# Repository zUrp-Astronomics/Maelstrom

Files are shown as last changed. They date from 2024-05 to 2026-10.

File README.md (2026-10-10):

<!-- zurp-readme-header:begin — paste this block once, never again: the poster and the badges update themselves at each build of the site — do not edit it -->
<div align="center">

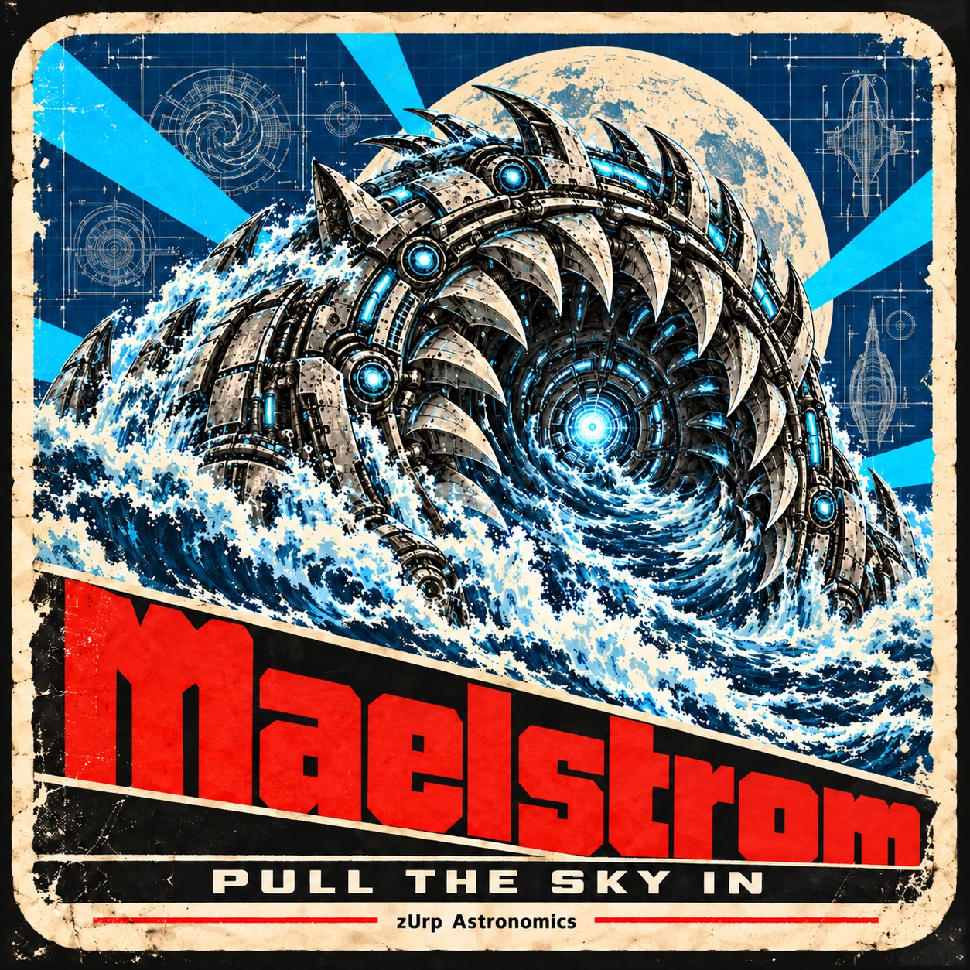
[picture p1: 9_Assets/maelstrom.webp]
zUrp Astronomics product poster



software licence
hardware licence

</div>

<!-- zurp-readme-header:end -->

<h1 align="center">Maelstrom</h1>

<p align="center"><strong><em>Pull the sky in.</em></strong></p>

<p align="center">
  <a href="https://zurp-astronomics.github.io/maelstrom/">Website</a> ·
  <a href="../../releases">Releases</a> ·
  <a href="https://github.com/zUrp-Astronomics">zUrp Astronomics</a>
</p>

---

<div align="center">

## 🚧 Work in progress — do not build yet 🚧

**Nothing here is validated on real hardware.**<br>
Files change without notice, and what you build today may need rework tomorrow.<br>
👀 Watch the repository to know when the first release lands.

</div>

---

## Why Maelstrom?

A cooled APS-C CCD astrocam usually costs more than a new CMOS camera. **Maelstrom cannibalises a
2006 DSLR instead**: the CCD of a Nikon D40 — APS-C, 6 Mpx, 7.8 µm pixels, the very sensor of the
QHY8 Pro — reborn behind active TEC cooling and a 16-bit readout chain, and headed for the body of
a ZWO planetary camera. Around **€40 per board**. Do the electronics yourself, and pull the sky in.

## At a glance

| | |
|---|---|
| Sensor | Nikon D40 CCD (Sony ICX453): APS-C, 6 Mpx, 7.8 µm pixels — same as the [QHY8 Pro](https://www.astroshop.de/fr/cameras-astronomiques/camera-qhy-8-pro-color/p,54748#specifications) |
| Readout | AD9826 16-bit ADC, FT2232H USB bridge, STM32F103 |
| Cooling | active TEC, opto-coupler and MOSFET isolated from the rest of the board |
| Boards | logic and power, v1.1 — round, 56 mm, components inside 48.5 mm |
| Link | USB type-B |
| Target body | the housing of a ZWO ASI224 planetary camera |
| Cost | 5 boards for €160 of fabrication, about €200 all in — around €40 each |

## Hardware

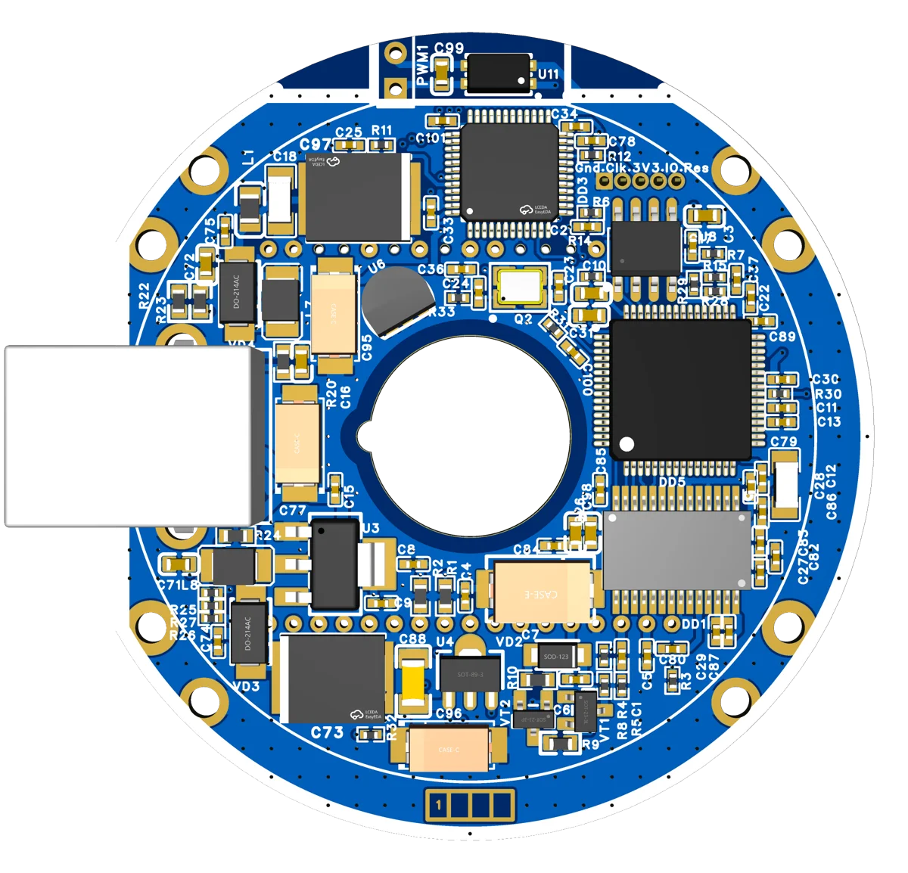
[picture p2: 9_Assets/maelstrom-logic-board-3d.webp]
Maelstrom logic board v1.1, 3D view


Maelstrom — formerly *Cam87 Redux* — starts from a design that already works: the author runs a
functional "box" version of the cam87. What it changes is the mechanics: three boards to assemble and
a fragile printed case become two round boards meant to fit the housing of a ZWO ASI224 — on
paper, it fits.

- **Layout.** Power, ADC, CCD horizontal and vertical drive and logic are kept as far apart as the
  56 mm allow; the supplies are decoupled with care, a capacitor wherever there was room.
- **Schematic updates.** Cooling redesigned around an isolated opto-coupler and MOSFET; decoupling
  added throughout; BoM reworked for cost and placement (down to 0402); back to a standard EEPROM.
- **Files.** Both v1.1 boards — logic and power — are in `1_Board/`; the cold plate, heatsink and
  camera design are in `2_Hardware/`. The source project is on
  [OSHWLab](https://oshwlab.com/lordzurp/cam87_redux).

## Status & roadmap

A variant is considered, with no file in this repository yet: a 48.5 mm round board, USB-C, and an
opto-coupler alone for the cooling, without the MOSFET.

## Credits

Maelstrom stands on the CAM86 and cam87 projects, which
pioneered the DSLR-sensor-reborn-as-astrocam approach; the cam87 is grim's (Gilmanov Rim).

## Repository layout

| Folder | Contents |
|---|---|
| [`0_Datasheets/`](0_Datasheets/) | datasheets of the components, as published by their makers |
| [`1_Board/`](1_Board/) | manufacturing files of the two v1.1 boards, one subfolder each: `Logic-board/`, `Power-board/` |
| [`2_Hardware/`](2_Hardware/) | mechanics: cold plate, heatsink, and the camera's design source (Fusion 360, STEP) |
| [`4_Firmware/`](4_Firmware/) | the cam87 STM32 firmware binary and the MProg template of the FT2232H EEPROM |
| [`5_App/`](5_App/) | Windows tools: FTDI MProg, and the cam87 viewer |
| [`8_References/`](8_References/) | external references: CAM86 and cam87 schematics, QHY8 Pro pictures |
| [`9_Assets/`](9_Assets/) | the showcase: product sheet, poster and README images |

## License

- **Hardware design** — boards, mechanics and 3D models: [Open Community License v1.1](LICENSE-HARDWARE).
- **Everything else** — firmware, software, documentation and images: [GNU GPL v3.0](LICENSE).

Third-party material keeps its own licence:

- the datasheets in `0_Datasheets/` and the documents in `8_References/` belong to their authors;
- MProg and its DLLs (`5_App/MProg 3.5 Release/`) are under FTDI's licence (`EULA.txt` in their folder);
- the viewer (`5_App/Viewer/`) and the firmware `4_Firmware/cam87 v1.0.bin` come from grim's (Gilmanov Rim) cam87, published without a licence; the `ftd2xx.dll` next to the viewer is FTDI's D2XX DLL;
- `4_Firmware/cam87.ept`, the MProg template of the cam87's FT2232H EEPROM, comes from the cam87 forums — most likely astroclub.kiev.ua, where grim's project was born (probable, not confirmed) — with no known licence.

---

<p align="center"><sub><a href="https://zurp-astronomics.github.io/">zUrp Astronomics</a> — a subsidiary of zUrp Industries. Because buying is cheating.</sub></p>

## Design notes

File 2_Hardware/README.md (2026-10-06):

La mécanique hors carte : la cold plate et le radiateur en STEP (avec le plan PDF du dessus de la cold plate), et la source de conception de la caméra, `Maelstrom_Camera`, en F3D et en STEP.

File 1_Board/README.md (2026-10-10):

Les fichiers de fabrication des deux cartes v1.1, tels que les sort l'outil de CAO : la carte logique dans `Logic-board/`, la carte d'alimentation dans `Power-board/`, chacune avec sa fiche `_0-README.txt`.

## Nommage des fichiers de carte

Les fichiers de `1_Board/` suivent le schéma :

```
Maelstrom-<Carte>-v<version>_<n>-<Nature>.<ext>
```

- `<Carte>` : `Logic-board` ou `Power-board`, le nom du sous-dossier ;
- `<version>` : la version de la carte, `1.1` ;
- `<n>-<Nature>` : la nature du fichier.

| n | fichier |
|---|---|
| 0 | `0-README.txt` : la fiche de la carte |
| 1 | `1-Schematics.pdf`, `1-Schematics.png` : le schéma |
| 2 | `2-view_top.png`, `2-view_bot.png` : vues du dessus et du dessous ; `2-view_3D.png`, `2-view_3D-bot.png`, `2-view_3D.step` : vues 3D du dessus et du dessous, et modèle 3D |
| 3 | `3-Gerber.zip` : Gerber RS-274X et perçages Excellon |
| 4 | `4-BoM.xlsx` : la nomenclature, références LCSC |
| 5 | `5-PnP.xlsx` : le placement, coordonnées en mm |

Exemple : `Maelstrom-Logic-board-v1.1_3-Gerber.zip`.

Les autres fichiers gardent leur nom : ceux de `2_Hardware/` (`Maelstrom_<Pièce>.<ext>`), et les
fichiers de tiers (datasheets, documents de référence, firmware, MProg, viewer).

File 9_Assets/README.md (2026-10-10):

# 9_Assets

The showcase of Maelstrom: what the [zUrp Astronomics website](https://zurp-astronomics.github.io/maelstrom/) and this repository's
README display. It belongs to the zUrp Astronomics organisation, which keeps it consistent across
all its products.

| File | What it is | Shown on |
|---|---|---|
| `zurp.yml` | the product sheet: name, tagline, slogan, section, status, description, accent colour | the website, the organisation README |
| `maelstrom.webp` | the poster, 1254 × 1254 | the website, the README header |
| `maelstrom-logic-board-3d.webp` | logic board v1.1, 3D view | the README |

Images here are WebP copies sized for display. Their full-size originals stay where they are produced: `1_Board/Logic-board/Maelstrom-Logic-board-v1.1_2-view_3D.png`.

The sheet is read and checked by the website at each build: its format is described in
[`content/README.md`](https://github.com/zUrp-Astronomics/zurp-astronomics.github.io/blob/main/content/README.md)
of the website's repository.

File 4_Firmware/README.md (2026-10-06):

Le firmware de la carte : le binaire STM32 de la cam87 (`cam87 v1.0.bin`) et le gabarit MProg de l'EEPROM du FT2232H (`cam87.ept`).

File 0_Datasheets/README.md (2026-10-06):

Les datasheets des composants utilisés, sous leur nom d'origine : PDF du fabricant, plus la feuille de calcul du MC34063 et le brochage de l'ICX453.

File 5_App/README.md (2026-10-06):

Les applications qui parlent au produit, chacune dans son dossier d'origine : MProg de FTDI, pour programmer l'EEPROM du FT2232H, et le viewer de la cam87.

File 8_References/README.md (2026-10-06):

Ce que le projet consulte, pas ce qu'il produit : les schémas de la CAM86 et de la cam87, et des images de la QHY8pro.

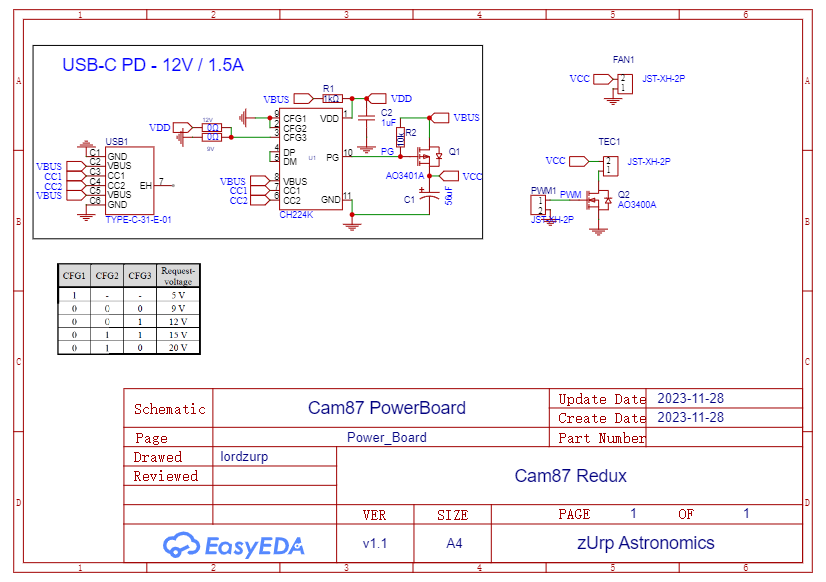
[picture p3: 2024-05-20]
1_Board/Power-board/Maelstrom-Power-board-v1.1_1-Schematics.png

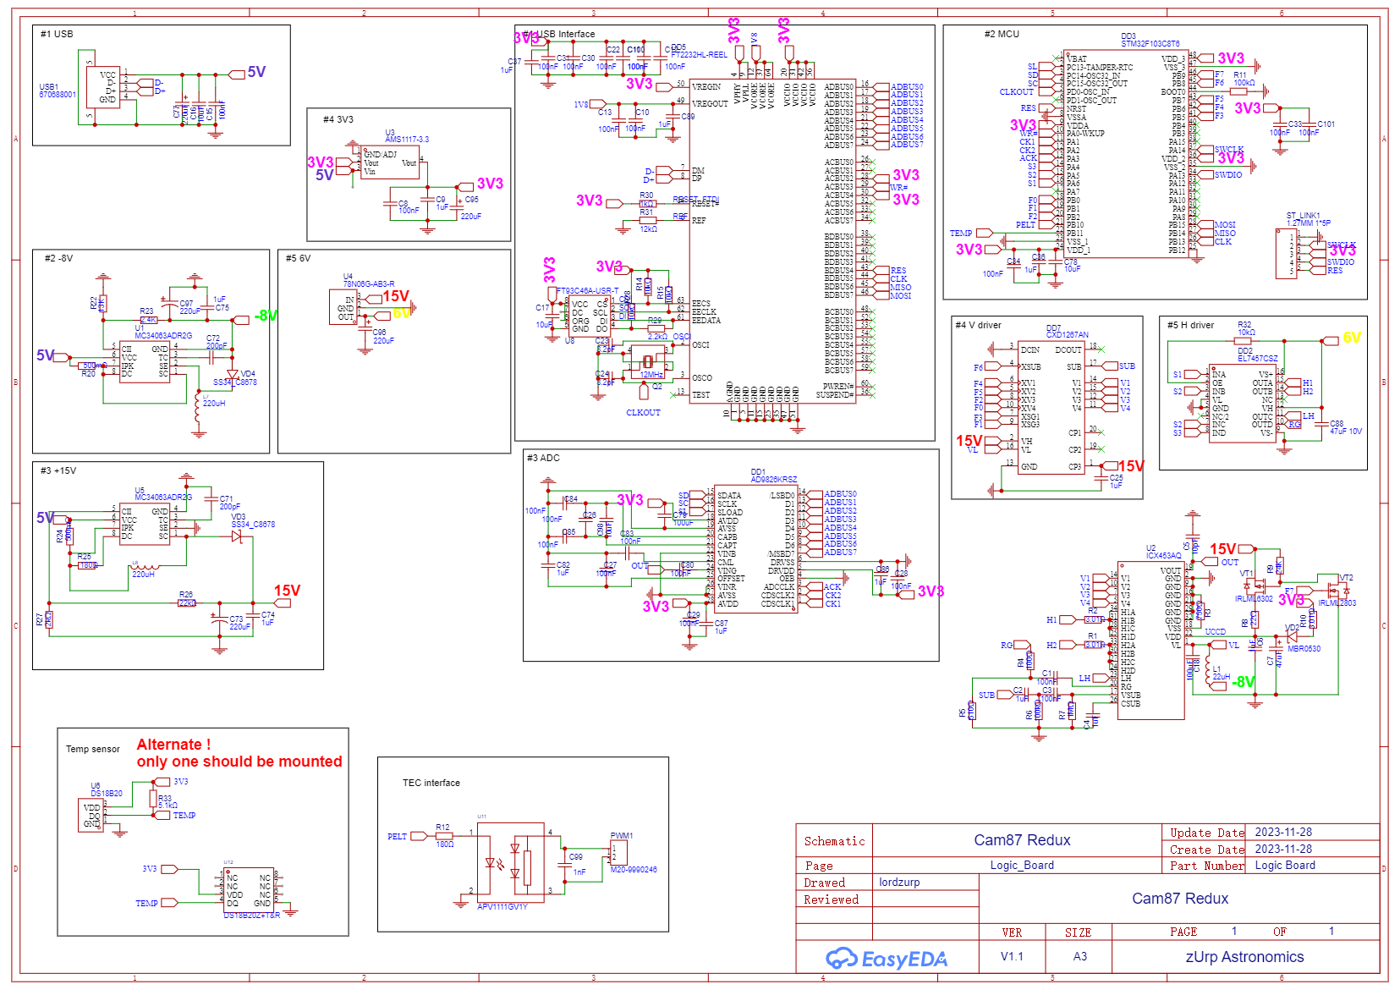
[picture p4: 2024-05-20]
1_Board/Logic-board/Maelstrom-Logic-board-v1.1_1-Schematics.png

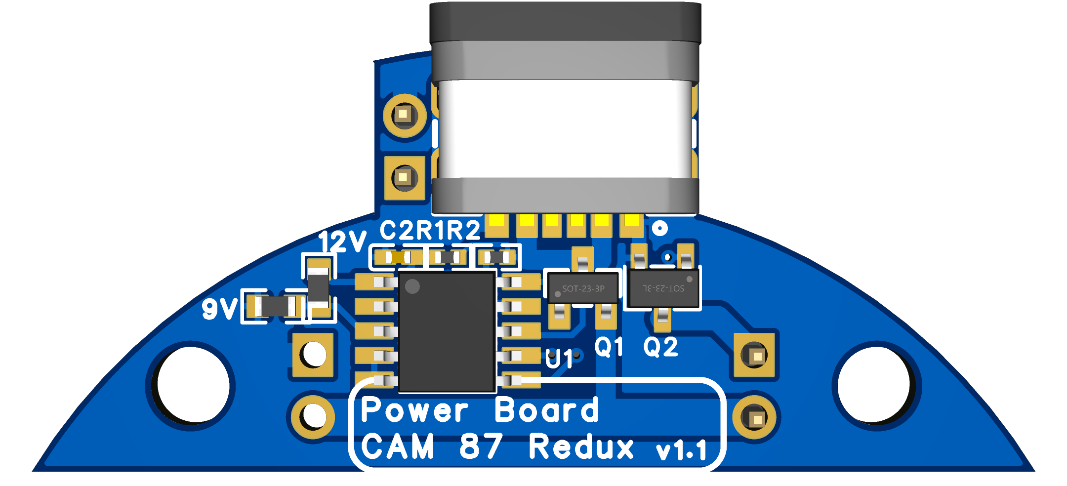
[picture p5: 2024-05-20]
1_Board/Power-board/Maelstrom-Power-board-v1.1_2-view_3D.png

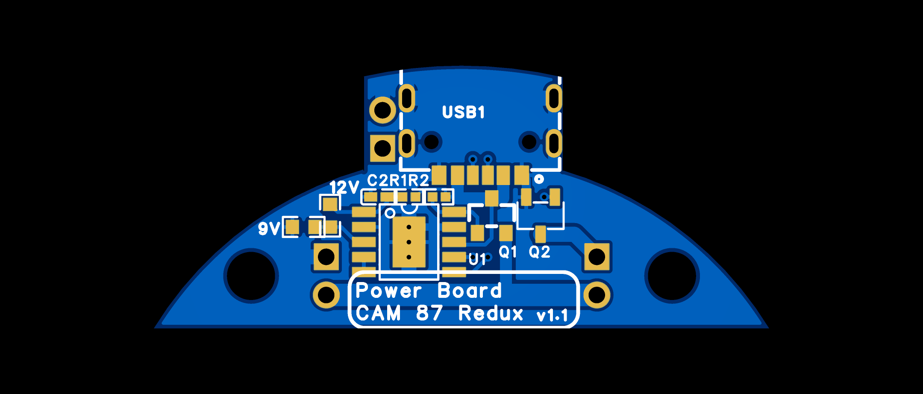
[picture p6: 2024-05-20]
1_Board/Power-board/Maelstrom-Power-board-v1.1_2-view_top.png

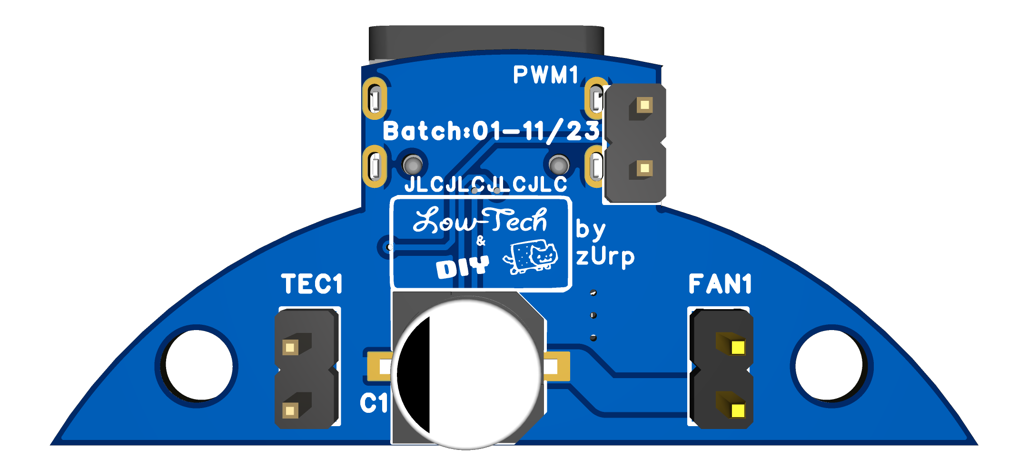
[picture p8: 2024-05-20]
1_Board/Power-board/Maelstrom-Power-board-v1.1_2-view_3D-bot.png

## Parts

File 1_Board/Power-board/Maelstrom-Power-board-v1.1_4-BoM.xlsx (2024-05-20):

No. | Quantity | Device | Designator | Footprint | Value | Manufacturer Part | Manufacturer | Supplier Part | Supplier | Add into BOM | Name | Primary Category | Secondary Category | JLCPCB Stock | JLCPCB Price | JLCPCB Part Class
1 | 1 | 0603WAF0000T5E | 12V | R0603 | 0Ω | 0603WAF0000T5E | UNI-ROYAL(厚声) | C21189 | LCSC | yes | 0Ω | Resistors | Chip Resistor - Surface Mount | 9418308 | 0.00645 | Basic Part
2 | 1 | OVZ560M1ETR-0606 | C1 | CAP-SMD_BD6.3-L6.6-W6.6-FD-A | 56uF | OVZ560M1ETR-0606 | lelon(立隆) | C250116 | LCSC | yes | 56uF |  |  | 635 | 1.237 | ExtendedPart
3 | 1 | CL05A105KA5NQNC | C2 | C0402 | 1uF | CL05A105KA5NQNC | SAMSUNG(三星) | C52923 | LCSC | yes | 1uF |  |  | 2774039 | 0.0237 | BasicPart
4 | 3 | JST-XH-2P-M | FAN1,PWM1,TEC1 | HDR-M-2.54_1X2 |  | JST-XH-2P-M | JST | JST-XH-2P-M |  | yes | JST-XH-2P |  |  | 0
5 | 1 | AO3401A_C15127 | Q1 | SOT-23_L2.9-W1.3-P1.90-LS2.4-BR |  | AO3401A | AOS | C15127 | LCSC | yes | AO3401A | Triode/MOS Tube/Transistor | MOSFETs | 235251 | 0.394 | BasicPart
6 | 1 | AO3400A_C20917 | Q2 | SOT-23-3_L2.9-W1.6-P1.90-LS2.8-BR |  | AO3400A | AOS | C20917 | LCSC | yes | AO3400A | Triode/MOS Tube/Transistor | MOSFETs | 30849 | 0.488 | BasicPart
7 | 1 | 0402WGF1001TCE | R1 | R0402 | 1kΩ | 0402WGF1001TCE | UNI-ROYAL(厚声) | C11702 | LCSC | yes | 1kΩ | Resistors | Chip Resistor - Surface Mount | 5855534 | 0.0031 | BasicPart
8 | 1 | 0402WGF1002TCE | R2 | R0402 | 10k | 0402WGF1002TCE | UNI-ROYAL(厚声) | C25744 | LCSC | yes |  |  |  | 8885566 | 0.00292 | BasicPart
9 | 1 | CH224K | U1 | ESSOP-10_L4.9-W3.9-P1.0-LS6.0-TL-EP |  | CH224K | WCH(南京沁恒) | C970725 | LCSC | yes | CH224K | Communication Interface Chip/UART/485/232 | USB ICs | 3287 | 3.22 | ExtendedPart
10 | 1 | TYPE-C-31-E-01 | USB1 | TYPE-C-SMD_TYPE-C-31-E-01 |  | TYPE-C-31-E-01 | 韩国韩荣 | C530618 | LCSC | yes | TYPE-C-31-E-01 |  |  | 128 | 5.94 | ExtendedPart

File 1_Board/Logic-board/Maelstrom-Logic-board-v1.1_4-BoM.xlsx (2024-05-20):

No. | Quantity | Device | Designator | Footprint | Value | Manufacturer Part | Manufacturer | Supplier Part | Supplier | Add into BOM | Name | Primary Category | Secondary Category | JLCPCB Stock | JLCPCB Price | JLCPCB Part Class
1 | 20 | CL05B104KB54PNC | C1,C3,C8,C11,C12,C13,C15,C22,C27,C28,C29,C30,C33,C34,C80,C83,C84,C85,C100,C101 | C0402 | 100nF | CL05B104KB54PNC | SAMSUNG(三星) | C307331 | LCSC | yes | 100nF | Capacitors | Multilayer Ceramic Capacitors MLCC - SMD/SMT | 3210689 | 0.0428 | Basic Part
2 | 13 | CL05A105KA5NQNC | C2,C4,C6,C9,C25,C36,C37,C74,C75,C82,C86,C87,C89 | C0402 | 1uF | CL05A105KA5NQNC | SAMSUNG(三星) | C52923 | LCSC | yes | 1uF |  |  | 2776105 | 0.0237 | Basic Part
3 | 1 | CL05C100JB5NNNC | C5 | C0402 | 10pF | CL05C100JB5NNNC | SAMSUNG(三星) | C32949 | LCSC | yes | 10pF |  |  | 187520 | 0.0343 | Basic Part
4 | 1 | TAJD476K025RNJ | C7 | CAP-SMD_L7.3-W4.3-R-RD |  | TAJD476K025RNJ | AVX | C7228 | LCSC | yes | 47uF |  |  | 9636 | 3.8 | Extend
5 | 3 | CC0603KRX7R9BB104 | C10,C26,C31 | C0603 | 100nF | CC0603KRX7R9BB104 | YAGEO(国巨) | C14663 | LCSC | yes | 100nF |  |  | 26465158 | 0.0142 | Basic Part
6 | 3 | CL10A106KP8NNNC | C16,C17,C98 | C0603 | 10uF | CL10A106KP8NNNC | SAMSUNG(三星) | C19702 | LCSC | yes | 10uF |  |  | 2289457 | 0.0338 | Basic Part
7 | 2 | CL31A107MQHNNNE | C18,C79 | C1206 | 100uF | CL31A107MQHNNNE | SAMSUNG(三星) | C15008 | LCSC | yes | 100uF |  |  | 97979 | 0.398 | Basic Part
8 | 2 | 0402CG8R2C500NT | C23,C24 | C0402 | 8.2pF | 0402CG8R2C500NT | FH(风华) | C1579 | LCSC | yes | 8.2pF |  |  | 18688 | 0.0064 | Extended Part
9 | 2 | 0603B201K500NT | C71,C72 | C0603 |  | 0603B201K500NT | FH | C1600 | LCSC | yes | 200pF |  |  | 46770 | 0.0227 | Basic
10 | 2 | TCN4227M025R0100 | C73,C97 | CAP-SMD_L7.3-W6.1_TCN4227M025R0100 | 220uF | TCN4227M025R0100 | Kyocera AVX | C2158994 | LCSC | yes | 220uF | Capacitors | Tantalum Capacitors | 763 | 18.69 | Extended Part
11 | 3 | TAJC227K010RNJ | C77,C95,C96 | CAP-SMD_L6.0-W3.2-R-RD | 220uF | TAJC227K010RNJ | Kyocera AVX | C8023 | LCSC | yes | 220uF |  |  | 564 | 3.22 | Extended Part
12 | 1 | CL05A106MQ5NUNC | C78 | C0402 | 10uF | CL05A106MQ5NUNC | SAMSUNG(三星) | C15525 | LCSC | yes | 10uF |  |  | 7094435 | 0.029 | Basic Part
13 | 1 | 47uF 10V | C88 | C1206 |  | CL31A476MPHNNNE | SAMSUNG | C96123 | LCSC | yes | 47uF 10V |  |  | 311116 | 0.466 | Basic
14 | 1 | CL10B102KB8NNNC | C99 | C0603 | 1nF | CL10B102KB8NNNC | SAMSUNG(三星) | C1588 | LCSC | yes | 1nF |  |  | 5179975 | 0.0169 | Basic Part
15 | 1 | AD9826KRSZ | DD1 | SSOP-28_L10.2-W5.3-P0.65-LS7.8-BL |  | AD9826KRSZ | ADI | C13734 | LCSC | yes | AD9826KRSZ |  |  | 1754 | 38.09 | Extend
16 | 1 | EL7457CSZ | DD2 | SOIC-16_L9.9-W3.9-P1.27-LS6.0-BL |  | EL7457CSZ | RENESAS(瑞萨)/IDT | C3655423 | LCSC | yes | EL7457CSZ |  |  | 0 | 49.68
17 | 1 | STM32F103C8T6 | DD3 | LQFP-48_L7.0-W7.0-P0.50-LS9.0-BL |  | STM32F103C8T6 | STMicroelectronics | C8734 | LCSC | yes | STM32F103C8T6 |  |  | 56433 | 8.93 | Basic
18 | 1 | FT2232HL-REEL | DD5 | LQFP-64_L10.0-W10.0-P0.50-LS12.0-TL |  | FT2232HL-REEL | FTDI(飞特帝亚) | C27882 | LCSC | yes | FT2232HL-REEL |  |  | 59 | 36.83 | Extended Part
19 | 1 | CXD1267AN | DD7 | TSSOP-20_L6.5-W4.4-P0.65-LS6.4-BL |  | Sony |  |  |  | yes | CXD1267AN
20 | 1 | CBC2012T220K | L1 | L0805 | 22uH | CBC2012T220K | TAIYO YUDEN(太诱) | C223184 | LCSC | yes | 22uH |  |  | 7 | 0.786 | Extended Part
21 | 2 | CBC3225T221KR | L7,L8 | L1210 | 220uH | CBC3225T221KR | TAIYO YUDEN(太诱) | C223231 | LCSC | yes | 220uH | Inductors/Coils/Transformers | Power Inductors | 262 | 0.642 | Extended Part
22 | 1 | 12MHz | Q2 | OSC-SMD_4P-L3.2-W2.5-BL |  | X322512MSB4SI | YXC | C9002 | LCSC | yes | 12MHz |  |  | 201387 | 0.372 | Basic
23 | 3 | 0603WAF301KT5E | R1,R2,R10 | R0603 | 3.01Ω | 0603WAF301KT5E | UNI-ROYAL(厚声) | C270936 | LCSC | yes | 3.01Ω |  |  | 28 | 0.0124 | Extended Part
24 | 1 | AC0402FR-07750RL | R3 | R0402 | 750Ω | AC0402FR-07750RL | YAGEO(国巨) | C227221 | LCSC | yes | 750Ω |  |  | 7573 | 0.0066 | Extended Part
25 | 1 | 0402WGF1000TCE | R4 | R0402 | 100Ω | 0402WGF1000TCE | UNI-ROYAL(厚声) | C25076 | LCSC | yes | 100Ω |  |  | 2005191 | 0.00292 | Basic Part
26 | 1 | 0402WGF5100TCE | R5 | R0402 | 510Ω | 0402WGF5100TCE | UNI-ROYAL(厚声) | C25123 | LCSC | yes | 510Ω |  |  | 386746 | 0.00303 | Basic Part
27 | 2 | 0402WGF1003TCE | R6,R11 | R0402 | 100kΩ | 0402WGF1003TCE | UNI-ROYAL(厚声) | C25741 | LCSC | yes | 100kΩ |  |  | 3170292 | 0.00301 | Basic Part
28 | 1 | 0402WGF1004TCE | R7 | R0402 | 1MΩ | 0402WGF1004TCE | UNI-ROYAL(厚声) | C26083 | LCSC | yes | 1MΩ |  |  | 1271919 | 0.00322 | Basic Part
29 | 1 | 0402WGF220JTCE | R8 | R0402 | 22Ω | 0402WGF220JTCE | UNI-ROYAL(厚声) | C25092 | LCSC | yes | 22Ω |  |  | 1354420 | 0.00305 | Basic Part
30 | 1 | 0603WAF2402T5E | R9 | R0603 |  | 0603WAF2402T5E | UniOhm | C23352 | LCSC | yes | 24K |  |  | 554806 | 0.00625 | Basic
31 | 2 | CRCW0402180RFKED | R12,R25 | R0402 | 180Ω | CRCW0402180RFKED | VISHAY(威世) | C481962 | LCSC | yes | 180Ω |  |  | 2673 | 0.04 | Extended Part
32 | 4 | 0402WGF1002TCE | R14,R15,R28,R32 | R0402 | 10kΩ | 0402WGF1002TCE | UNI-ROYAL(厚声) | C25744 | LCSC | yes | 10kΩ |  |  | 8896301 | 0.00292 | Basic Part
33 | 2 | HP03W5F500LT5E | R20,R24 | R0603 | 500mΩ | HP03W5F500LT5E | UNI-ROYAL(厚声) | C414986 | LCSC | yes | 500mΩ |  |  | 2025 | 0.202 | Extended Part
34 | 1 | 0603WAF1302T5E | R22 | R0603 |  | 0603WAF1302T5E | UniOhm | C22797 | LCSC | yes | 13K |  |  | 313642 | 0.00617 | Basic
35 | 1 | 0603WAF2401T5E | R23 | R0603 |  | 0603WAF2401T5E | UniOhm | C22940 | LCSC | yes | 2.4K |  |  | 306378 | 0.00609 | Basic
36 | 1 | 0402WGF2202TCE | R26 | R0402 | 22kΩ | 0402WGF2202TCE | UNI-ROYAL(厚声) | C25768 | LCSC | yes | 22kΩ |  |  | 530038 | 0.00306 | Basic Part
37 | 1 | 0402WGF2001TCE | R27 | R0402 | 2kΩ | 0402WGF2001TCE | UNI-ROYAL(厚声) | C4109 | LCSC | yes | 2kΩ |  |  | 2420582 | 0.00303 | Basic Part
38 | 1 | 0402WGF2201TCE | R29 | R0402 | 2.2kΩ | 0402WGF2201TCE | UNI-ROYAL(厚声) | C25879 | LCSC | yes | 2.2kΩ |  |  | 795002 | 0.0031 | Basic Part
39 | 1 | 0402WGF1001TCE | R30 | R0402 | 1kΩ | 0402WGF1001TCE | UNI-ROYAL(厚声) | C11702 | LCSC | yes | 1kΩ |  |  | 5857364 | 0.0031 | Basic Part
40 | 1 | 0402WGF1202TCE | R31 | R0402 | 12kΩ | 0402WGF1202TCE | UNI-ROYAL(厚声) | C25752 | LCSC | yes | 12kΩ |  |  | 459663 | 0.00311 | Basic Part
41 | 1 | 0402WGF5101TCE | R33 | R0402 | 5.1kΩ | 0402WGF5101TCE | UNI-ROYAL(厚声) | C25905 | LCSC | yes | 5.1kΩ |  |  | 1149428 | 0.00315 | Basic Part
42 | 2 | MC34063ADR2G | U1,U5 | SOIC-8_L5.0-W4.0-P1.27-LS6.0-BL |  | MC34063ADR2G | ON | C32078 | LCSC | yes | MC34063ADR2G |  |  | 18536 | 3.57 | Basic
43 | 1 | Sony | U2 | ICX453AQ |  | Sony |  |  |  | yes | ICX453AQ
44 | 1 | AMS1117-3.3 | U3 | SOT-223-3_L6.5-W3.4-P2.30-LS7.0-BR |  | AMS1117-3.3 | AMS | C6186 | LCSC | yes | AMS1117-3.3 |  |  | 383760 | 0.887 | Basic
45 | 1 | 78N06G-AB3-R | U4 | SOT-89-3_L4.5-W2.5-P1.50-LS4.2-BR |  | 78N06G-AB3-R | UTC | C84863 | LCSC | yes | 78N06G-AB3-R |  |  | 8726 | 0.359 | Extend
46 | 1 | FT93C46A-USR-T | U8 | SOP-8_L4.9-W3.9-P1.27-LS6.0-BL |  | FT93C46A-USR-T | FMD(辉芒微) | C2902369 | LCSC | yes | FT93C46A-USR-T | Memory | EEPROM | 150 | 0.692 | Extended Part
47 | 1 | APV1111GV1Y | U11 | SSOP-4_L4.5-W2.6-P1.27-LS4.8-TL |  | APV1111GV1Y | PANASONIC(松下) | C2977173 | LCSC | yes | APV1111GV1Y | Optocoupler/LED/Digital Tube/Photoelectric Device | Optocouplers - Logic Output | 301 | 21.94 | Extended Part
48 | 1 | DS18B20Z+T&R | U12 | SOIC-8_L4.9-W3.9-P1.27-LS6.0-BL |  | DS18B20Z+T&R | ADI(亚德诺)/MAXIM(美信) | C97190 | LCSC | yes | DS18B20Z+T&R | Sensors | Temperature Sensors | 2322 | 9.39 | Extended Part
49 | 1 | MBR0530T1G | VD2 | SOD-123_L2.8-W1.8-LS3.7-RD |  | MBR0530T1G | ON | C82046 | LCSC | yes | MBR0530 |  |  | 39033 | 0.654 | Extend
50 | 2 | SS34 | VD3,VD4 | DO-214AC_L4.3-W2.7-LS5.3-RD |  | SS34 | MDD | C8678 | LCSC | yes | SS34_C8678 |  |  | 964662 | 0.145 | Basic
51 | 1 | IRLML6302TRPBF | VT1 | SOT-23-3_L2.9-W1.6-P1.90-LS2.8-BR |  | IRLML6302TRPBF | IR | C24097 | LCSC | yes | IRLML6302 |  |  | 29721 | 0.831 | Extend
52 | 1 | IRLML2803TRPBF | VT2 | SOT-23-3_L2.9-W1.3-P1.90-LS2.4-BR |  | IRLML2803TRPBF | Infineon | C2590 | LCSC | yes | IRLML2803 |  |  | 0 | 0.733 | Extend

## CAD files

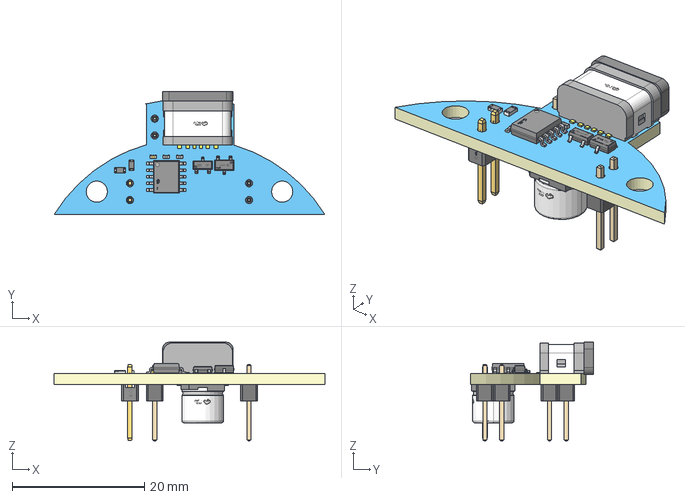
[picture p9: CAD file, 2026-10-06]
1_Board/Power-board/Maelstrom-Power-board-v1.1_2-view_3D.step
40.9 x 18.7 x 14.9 mm

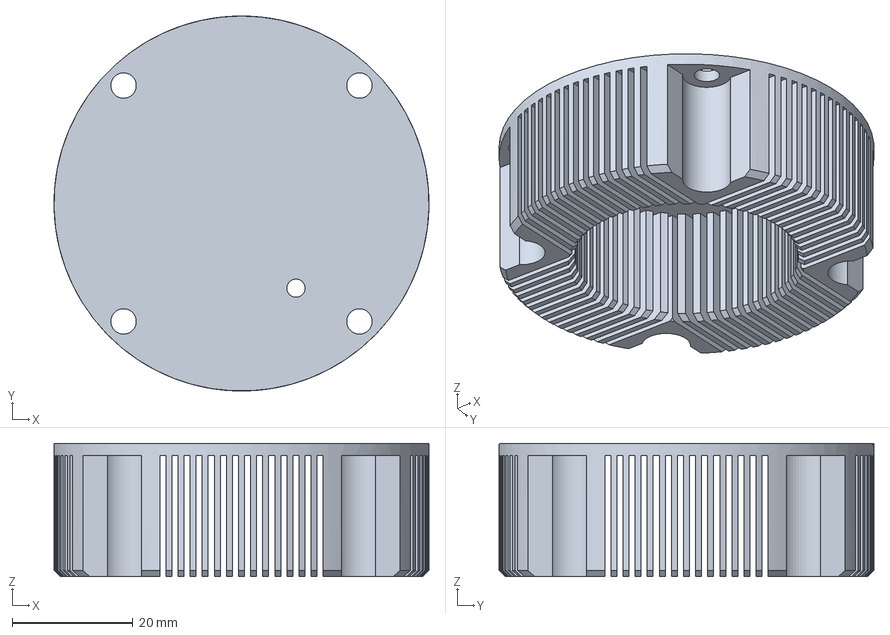
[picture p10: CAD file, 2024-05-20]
2_Hardware/Maelstrom_Camera.step
62.0 x 62.0 x 22.0 mm

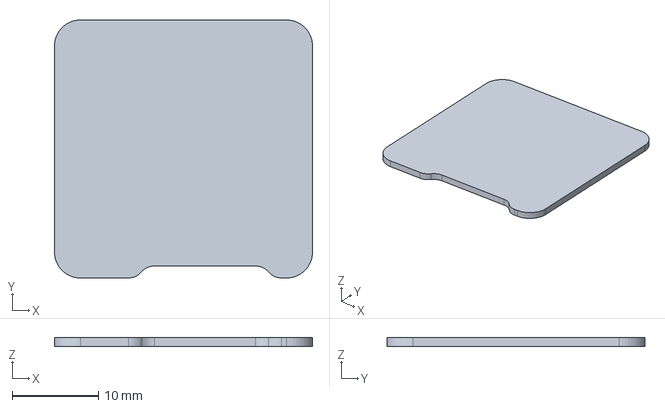
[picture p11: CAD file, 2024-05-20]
2_Hardware/Maelstrom_ColdPlate-BotPlate.step
30.0 x 30.0 x 1.00 mm

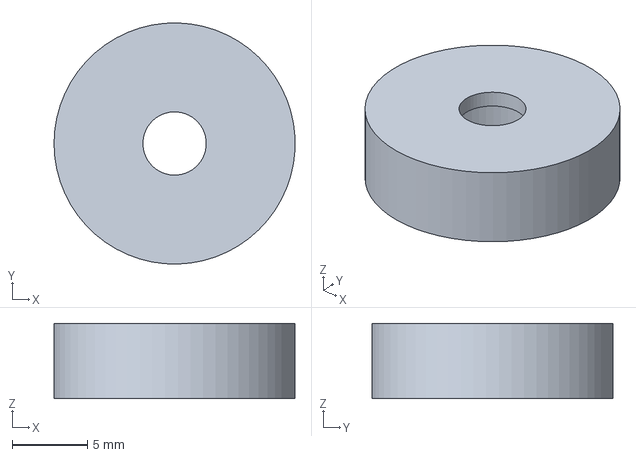
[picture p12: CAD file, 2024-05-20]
2_Hardware/Maelstrom_ColdPlate-BotCore.step
16.0 x 16.0 x 5.00 mm

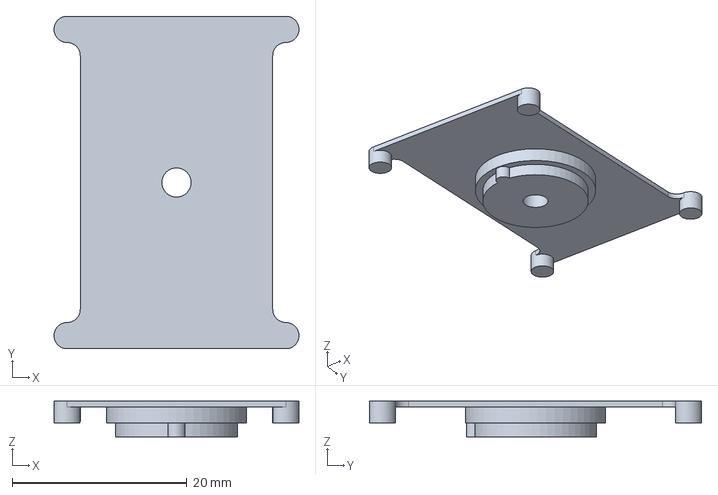
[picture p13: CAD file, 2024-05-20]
2_Hardware/Maelstrom_ColdPlate-Top.step
28.0 x 38.0 x 4.10 mm

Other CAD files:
2_Hardware/Maelstrom_Heatsink.step
2_Hardware/Maelstrom_Camera.f3d

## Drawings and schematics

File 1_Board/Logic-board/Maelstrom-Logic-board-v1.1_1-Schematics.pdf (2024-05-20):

### #1 USB

#4 3V3

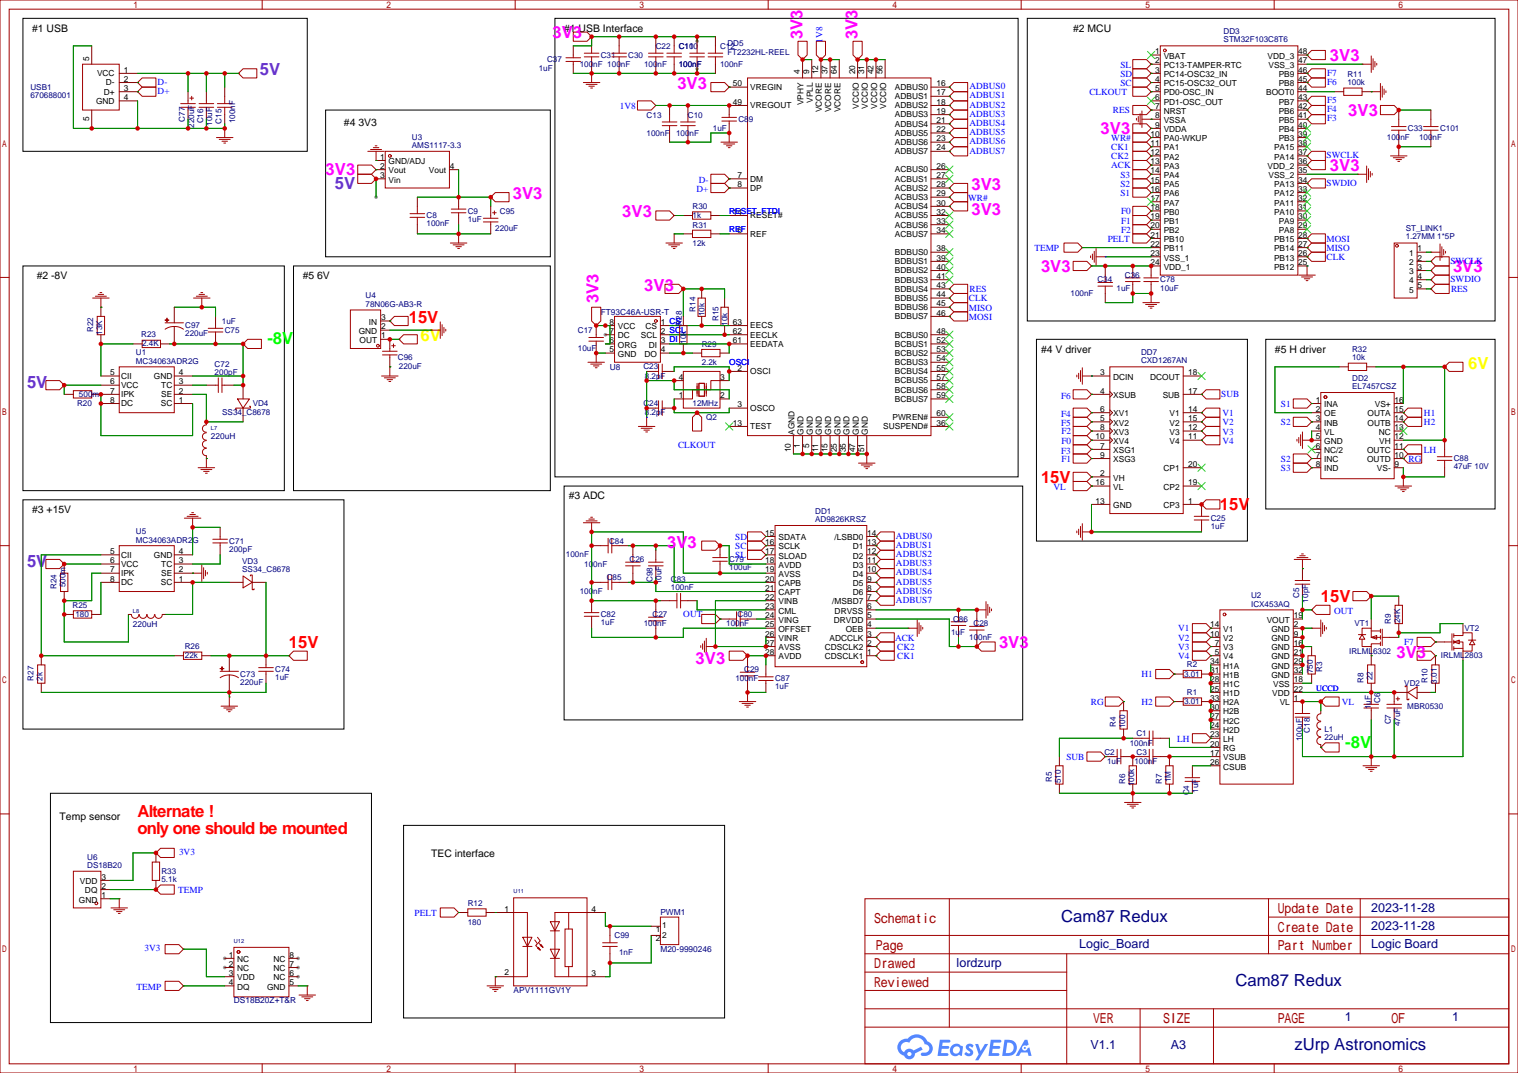
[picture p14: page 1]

only one should be mounted

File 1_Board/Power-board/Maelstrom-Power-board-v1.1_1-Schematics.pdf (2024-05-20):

# USB-C PD - 12V / 1.5A

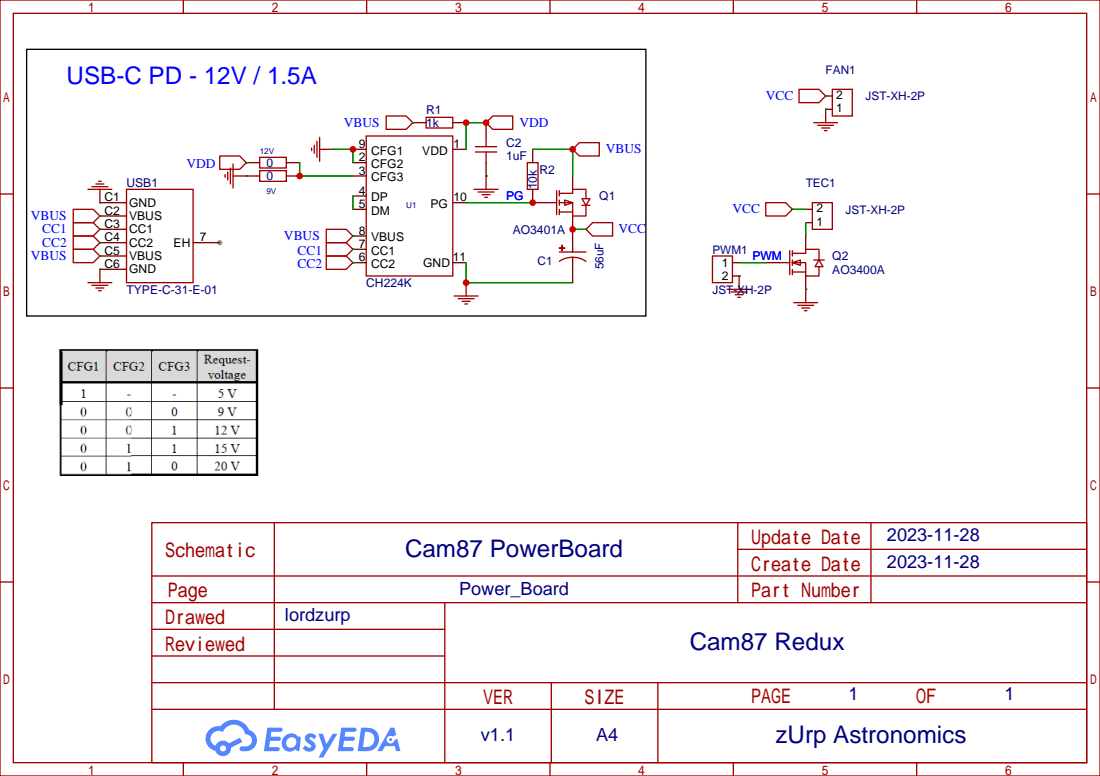
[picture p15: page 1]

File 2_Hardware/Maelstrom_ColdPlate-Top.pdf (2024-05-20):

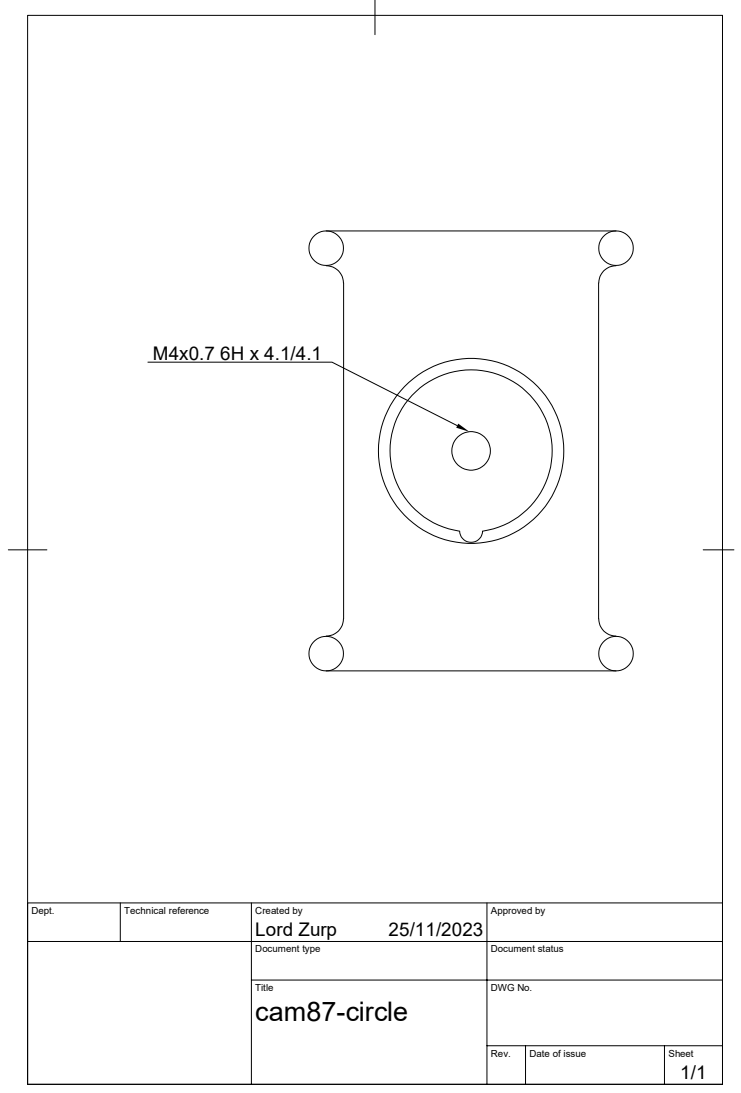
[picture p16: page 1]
Dept.; Technical reference; Created by; Approved by; Document type; Document status; Title; DWG No.; Rev.; Date of issue; Sheet; cam87-circle; Lord Zurp

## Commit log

2024-05-20 pop repo
    [Cam87_Redux - Cold_plate - bot_core.step, Cam87_Redux - Cold_plate - bot_plate.step, Cam87_Redux - Cold_plate - top.step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]
2026-10-03 chore(import-externe): déclaration de criticité (.lcars.json)
2026-10-03 ci(import): rail CI du depot (.gitea/workflows)
2026-10-06 feat(site): vitrine zUrp — 9_Assets/ et workflow zurp-site, posés tels quels depuis le kit du site
    Kit ready-room/site-maelstrom_workshop.zip (sha256 75985ee4…a68c),
    fichiers identiques à l'octet (sha256 vérifiés). Ticket #4.
    Claude-Session: https://claude.ai/code/session_01JkeaqfyitvVxvgP6FykwV1
2026-10-06 fix(site): zurp.yml — le statut est décidé par l'humain, pas par une release
    Corrige deux commentaires de 9_Assets/zurp.yml qui faisaient passer le
    produit en « released » dès qu'une release GitHub existe. Une release ne
    donne que la version affichée (son tag) et le rang dans la section ; le
    statut (wip | future | released) est écrit dans la fiche et décidé par
    l'humain. Données YAML inchangées.
    Claude-Session: https://claude.ai/code/session_01Qsyq5bGS8EnZmDohAf4kco
2026-10-06 refactor(repo): arborescence 0_…9_ au canon zUrp et README refondu
    - rangement par git mv (blobs inchangés) : 0_Datasheets, 1_Board/{Logic,Power}_board,
    2_Hardware, 3_3D-Models, 4_Firmware, 5_App, 8_References ;
    - fichiers de conception renommés Maelstrom_<Pièce>[_<version|date>][_<rang>_<doc>] ;
    - doublons à l'octet de la racine (Cam87_Redux.f3d/.step) supprimés ;
    - README : bloc d'en-tête zUrp en tête, texte de l'humain conservé,
    sections Arborescence et Licence.
    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
    [Cam87_Redux.f3d, Cam87_Redux.step, MC34063 DWS.XLS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]
2026-10-06 docs(readme): origine probable de cam87.ept — forums de la cam87, très probablement astroclub.kiev.ua
    Claude-Session: https://claude.ai/code/session_012NVZZjjQwiZYRfdeVsthva
2026-10-06 refactor(repo): mise au canon MAJ-DEPOTS-PRODUIT — cartes, 2_Hardware, README de dossier, licences, workflow
    - 1_Board : Logic-board/ et Power-board/, fichiers au schéma
    Maelstrom-<Carte>-v1.1_<n>-<Nature>.<ext> (git mv), fiche _0-README.txt par carte
    - 2_Hardware reçoit Maelstrom_Camera.f3d/.step ; 3_3D-Models disparaît,
    Maelstrom_PowerBoard_2024-03-09.step retiré
    - README.md d'une phrase dans chaque dossier de premier niveau
    - LICENSE-HARDWARE : OCL v1.1, texte officiel ; LICENSE (GPL-3) inchangé
    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
    [Maelstrom-Logic-board-v1.1_4-BoM.xlsx, Maelstrom-Logic-board-v1.1_5-PnP.xlsx, Maelstrom-Power-board-v1.1_2-view_3D.step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]
2026-10-06 feat(assets): vitrine — affiche Maelstrom 2.6 « Pull the sky in »
    Remplace 9_Assets/maelstrom.webp par l'affiche 2.6 (WebP VP8 1254×1254,
    copiée à l'octet depuis reference/zurp/maelstrom-2.6.webp, sha256
    1a6768a8…2ccfab) et met à jour slogan, posterAlt et accent (#04c8fd)
    dans 9_Assets/zurp.yml.
    Claude-Session: https://claude.ai/code/session_01FaVZApg54jgTdyXunNQEMm
2026-10-10 docs(vitrine): vitrine au cordeau — README, 9_Assets, licences (#19)
    - README.md, 9_Assets/README.md, 1_Board/README.md : annexes A, B, C du mandat, à l'octet
    - 9_Assets/maelstrom-logic-board-3d.webp : vue 3D de la carte logique v1.1, WebP q85, 1200 px
    - LICENSE : texte officiel GPL-3.0 (md5 1ebbd3e34237af26da5dc08a4e440464)
    - LICENSE-HARDWARE et .github/workflows/zurp-site.yml déjà conformes (md5 vérifiés)
    Claude-Session: https://claude.ai/code/session_016HkTGsQLz1o2Re7G6muuHV
